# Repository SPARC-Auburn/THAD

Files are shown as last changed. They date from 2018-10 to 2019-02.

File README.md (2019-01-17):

# THAD
## The Helpful Automated Defender  

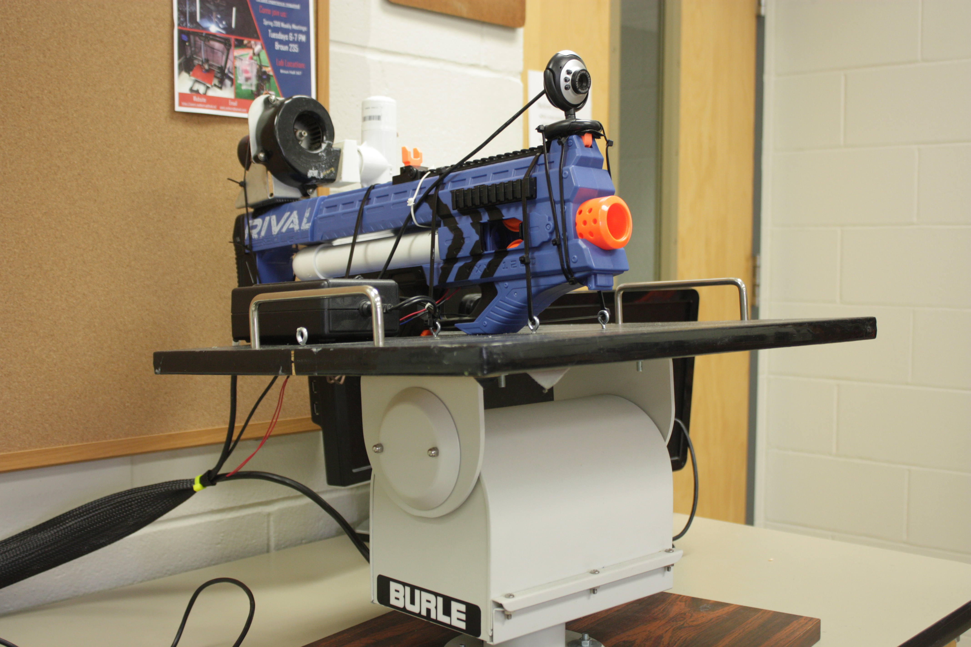
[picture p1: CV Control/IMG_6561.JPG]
THAD


## Project Purpose

THAD was previously a senior design project, and was given to SPARC in a state that did not operate. The goal of the project was to return it to working order and enable it with computer vision to be able to shoot the user's hand. This will facilitate a great project for demos and shows.

## Project Overview (NEEDS UPDATE)

The turret itself is mounted on a large, 2 axis motor, using a Nerf gun and seperate blower as its firing mechanism. The turret is controlled by a 5V 8-relay module to an Arduino. The arduino responds to serial commands. These commands are sent from various sources, and all that is required are (W,A,S,D,Q) characters to be sent over serial to operate. (These are Up, Left, Down, Right, and Fire respectively)

Using these serial commands, automatic control is also possible through OpenCV. The current version uses face recognition to determine targets, then crops a portion of the screen where the right hand might be relative to that face. Using the cropped image, it attempts to detect a right hand in a clenched fist. Future versions will ideally be able to handle multiple targets and a new haar cascade for an open hand.

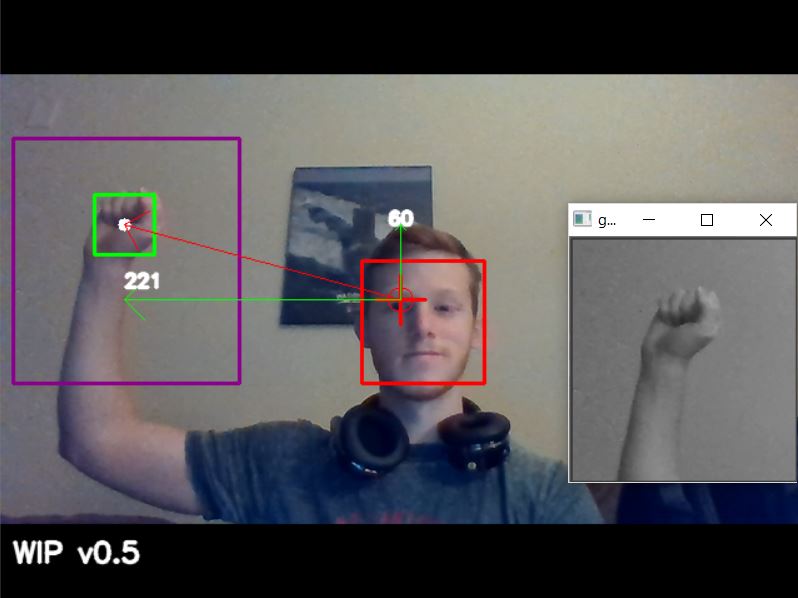
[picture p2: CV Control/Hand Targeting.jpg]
Face Recognition


## Setup and Use

### Manual (NEEDS UPDATE)

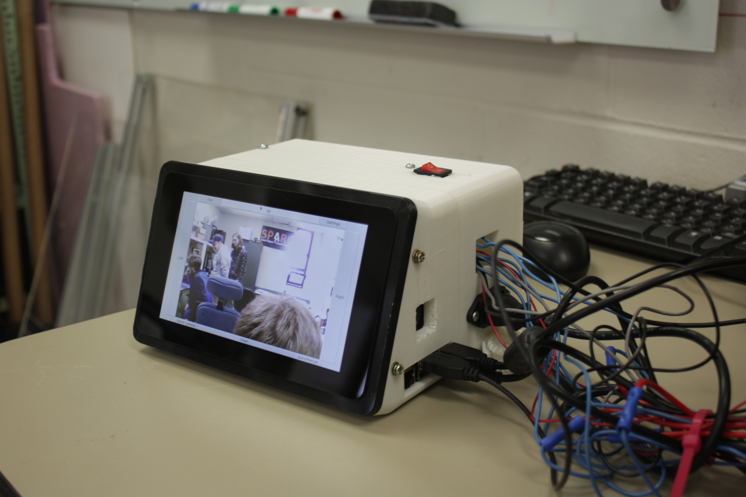
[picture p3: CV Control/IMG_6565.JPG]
Control Box


To run the turret manually via keyboard: 
1. Upload the .ino file located in the Manual folder to the Arduino. 
1. The Arduino pinout should be as follows:
  * DIO2 - Fire(Fan)
  * DIO3 - Flywheel(Trigger)
  * DIO4 - Up
  * DIO5 - Down
  * DIO6 - CW(Right)
  * DIO7 - CCW(Left)
  * Note: The Fan requires 27VDC
3. With the a PC still plugged in to the Arduino, run the keyboardserial.py program
  * You may have to change the port in the .py code. Simply change "COM3" to the port the Arduino is plugged into.
4. With the PyGame window active, use the keys W,A,S,D and Q to control the turret.  

### OpenCV(Computer Vision) (NEEDS UPDATE)

To run the turret via OpenCV:
1. Ensure Python 2.7 and OpenCV are compiled and usable natively from your OS Path.
1. Follow Step 2 from above to properly wire the turret.
1. Plug your computer into the webcam and Arduino located on THAD
1. Run the main.py program- it will currently only fire at a person's hand, and does not work well with multiple faces detected in the frame.
1. Get ready!

## Future Improvements

## References

1. "Hand-raising gesture detection with Lienhart-Maydt method in videoconference and distance learning" http://conteudo.icmc.usp.br/pessoas/moacir/papers/NazarePonti_CIARP2013.pdf

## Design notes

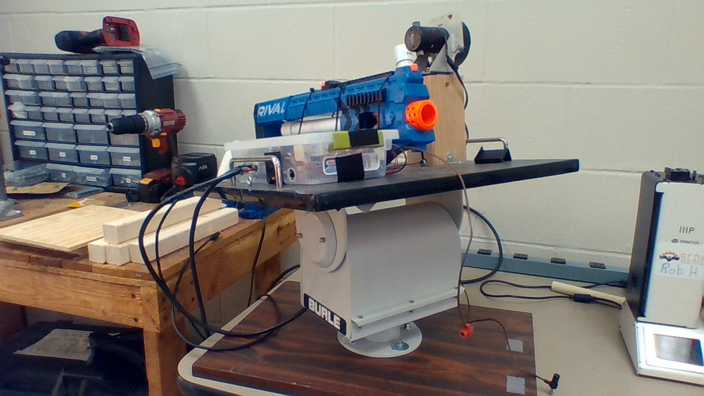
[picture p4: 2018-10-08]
img.jpg

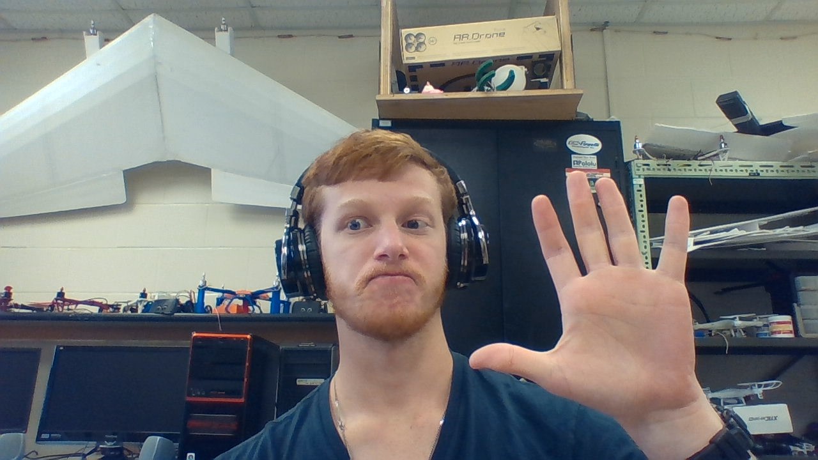
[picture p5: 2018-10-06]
CV_Control/handphoto.jpg

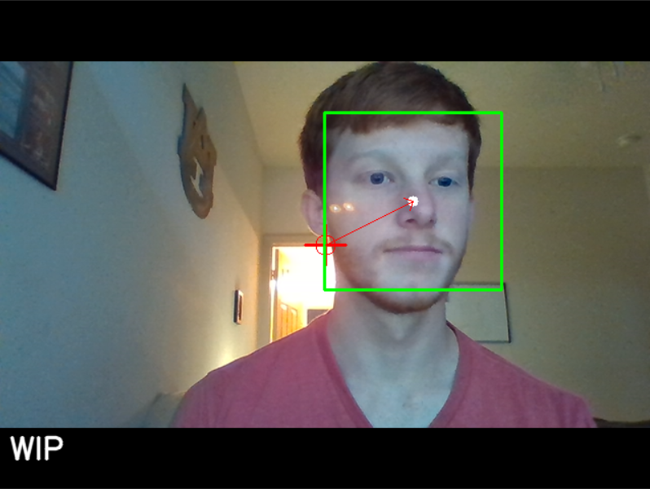
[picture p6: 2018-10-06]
CV_Control/Face Targeting.PNG

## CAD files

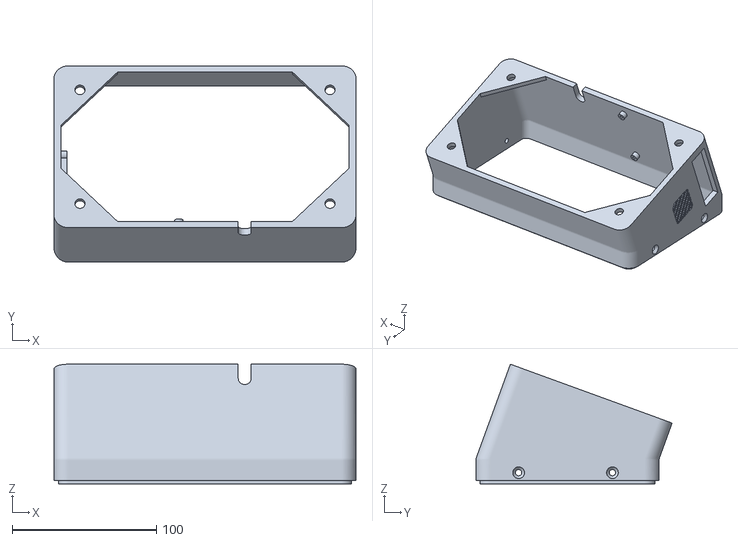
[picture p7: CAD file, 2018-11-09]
Control_Box/Wallmount_Back.stl
209.2 x 136.0 x 82.9

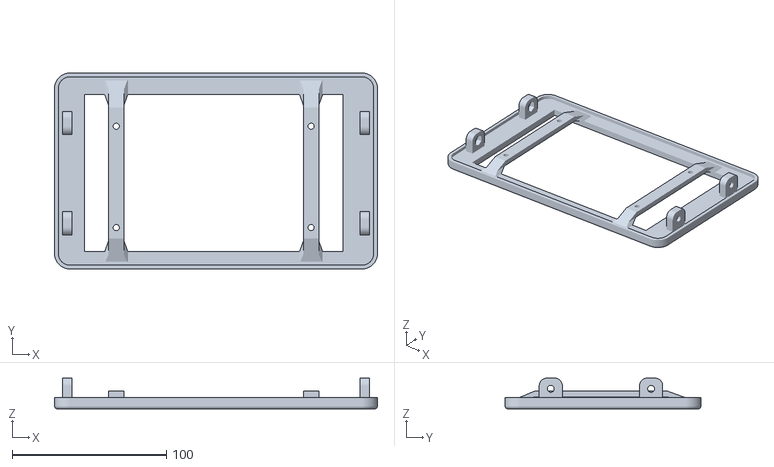
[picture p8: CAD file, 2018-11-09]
Control_Box/Wallmount_Front_Tessellation.3_1.stl
209.2 x 127.0 x 20.0

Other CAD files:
Control_Box/THAD Back.ipt

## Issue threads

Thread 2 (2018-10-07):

Webcam mount

joshjab, 2018-10-07:

joshjab, 2018-10-15:
Webcam is currently loosely attached to the Nerf gun's built in sight

joshjab, 2018-11-02:
Webcam mounted on top of turret

Closed 2018-11-02.

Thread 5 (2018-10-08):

Standalone Power Supply

joshjab, 2018-10-08:

joshjab, 2018-10-15:
Pi - 5VDC, 2A (Max)
Turret - 120VAC, ?A
Blower - 27VDC, .7A (Max)

joshjab, 2018-11-02:
Will be powered via 120VAC, removing this issue

Closed 2018-11-02.

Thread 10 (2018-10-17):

Swap out Arduino for Raspberry Pi GPIO

joshjab, 2018-10-17:

joshjab, 2018-11-02:
Duplicate Issue

Closed 2018-11-02.

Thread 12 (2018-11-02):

Ordering Parts

joshjab, 2018-11-02:
Needs:
- Pi Screen /w cable
AC/DC Converter
Wall plug w/ Female adapter

joshjab, 2018-11-02:
Power Switch

joshjab, 2018-11-05:
Parts ordered, except for PS

Closed 2018-11-05.

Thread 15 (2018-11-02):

Compile OpenCV on Pi and verify camera operation

joshjab, 2018-11-02:

joshjab, 2018-11-05:
Camera and detection works on Pi- new software release to come

joshjab, 2018-11-07:
Pi directly on turret does not work as expected. Reopening this issue

joshjab, 2018-11-09:
Fixed an issue with the haarcascades not properly being found. Camera works again- albeit slowly

Closed 2018-11-09.

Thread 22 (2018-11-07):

CAD Blower Joint

joshjab, 2018-11-07:
Old joint does not fit blower properly

joshjab, 2018-11-28:
Blower joint made and still is not a perfect fit- but it is adequate. May reopen this issue for V2

Closed 2018-11-28.

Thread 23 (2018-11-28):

Pi OpenCV Optimization

joshjab, 2018-11-28:
Recompiling OpenCV with better processor flags

joshjab, 2018-12-05:
Standalone optimization completed - still only 1 FPS, further improvement could be done- but it is no longer a current issue

Closed 2018-12-05.

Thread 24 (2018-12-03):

Restart USB when camera crashes

joshjab, 2018-12-03:

joshjab, 2018-12-06:
Reset Camera button added temporarily. Resets USB port and changes the index of the camera source back and forth from 0 to 1. Apparently the index changes when the camera reconnects

Closed 2018-12-06.

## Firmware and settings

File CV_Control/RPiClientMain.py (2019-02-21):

import Tkinter
import cv2
import PIL.Image, PIL.ImageTk
import time 
import socket
import numpy as np
import struct
pi = False
if pi:
    import RPi.GPIO as GPIO
    from USBReset import reset_USB_Device

##CONSTANTS##
#Pixel error margins
XMARGIN = 15
YMARGIN = 15  
#Camera position offsets
OFFSETX = 0
OFFSETY = 0
Pt1Y = 0
Pt2Y = 0
Pt2X = 0
Pt1X = 0
# Target Matched Variables (Controls firing)
XMatched = False
YMatched = False
#GPIO Pins UPDATE AS NEEDED
UP = 17
DOWN = 27
LEFT = 22
RIGHT = 23
FLYWHEEL = 24
BLOWER = 25
#Dev variables
standalone = 0
TCP_IP = '127.0.0.1'
PORT = 5005
font = cv2.FONT_HERSHEY_SIMPLEX

#RPi Setup
def GPIO_setup():
    GPIO.setmode(GPIO.BCM)
    GPIO.setwarnings(False)
    GPIO.setup(UP, GPIO.OUT)
    GPIO.setup(DOWN, GPIO.OUT)
    GPIO.setup(LEFT, GPIO.OUT)
    GPIO.setup(RIGHT, GPIO.OUT)
    GPIO.setup(FLYWHEEL, GPIO.OUT)
    GPIO.setup(BLOWER, GPIO.OUT)
    #Initial State Off
    GPIO.output(UP, GPIO.HIGH)
    GPIO.output(DOWN, GPIO.HIGH)
    GPIO.output(LEFT, GPIO.HIGH)
    GPIO.output(RIGHT, GPIO.HIGH)
    GPIO.output(FLYWHEEL, GPIO.HIGH)
    GPIO.output(BLOWER, GPIO.HIGH)

# Turret Control Function



def turnTurret( direction ):
    if(direction=="stopX"):
        GPIO.output(LEFT, GPIO.HIGH)   
        GPIO.output(RIGHT, GPIO.HIGH)
        print("X Matched")
    elif(direction=="stopY"):
        GPIO.output(UP, GPIO.HIGH)
        GPIO.output(DOWN, GPIO.HIGH)
        print("Y Matched")
    else:
        if(direction=="up"):
            GPIO.output(UP, GPIO.LOW)
            print("Moving up")
        elif(direction=="down"):
            GPIO.output(DOWN, GPIO.LOW)
            print("Moving down")
        elif(direction=="left"):
            GPIO.output(LEFT, GPIO.LOW)
            print("Moving left")
        elif(direction=="right"): 
            GPIO.output(RIGHT, GPIO.LOW)
            print("Moving right")

# Turret Fire Function

def fireTurret():
    GPIO.output(FLYWHEEL, GPIO.LOW)
    GPIO.output(BLOWER, GPIO.LOW)

#GPIO_setup() #UNCOMMENT THIS LINE FOR RUNNING ON RASPBERRY PI

 
class App:
    def __init__(self, window, window_title, video_source):
        self.window = window
        self.window.title(window_title)
        self.window.attributes('-fullscreen', True)
        self.video_source = video_source
        # open video source (by default this will try to open the computer webcam)
        self.vid = MyVideoCapture(self.video_source)
        self.autoMode = False
        self.standalone = Tkinter.BooleanVar()
        self.standalone.set(standalone)
        self.frame1 = Tkinter.Frame(window)
        self.frame1.pack()
        # Fire Button
        self.btn_fire=Tkinter.Button(self.frame1, text="Fire", width=10)
        self.btn_fire.pack(side=Tkinter.LEFT, anchor=Tkinter.NW, expand=True)
        self.btn_fire.bind('<ButtonPress-1>', self.fireon)
        self.btn_fire.bind('<ButtonRelease-1>', self.fireoff)
        # Up Button
        self.btn_up=Tkinter.Button(self.frame1, text="Up", width=50)
        self.btn_up.pack(side = Tkinter.LEFT, anchor=Tkinter.N, expand=True)
        self.btn_up.bind('<ButtonPress-1>', self.up)
        self.btn_up.bind('<ButtonRelease-1>', self.y_stop)
        # Settings Button
        self.btn_settings=Tkinter.Button(self.frame1, text="Settings", width=10, command=self.settings)
        self.btn_settings.pack(side = Tkinter.LEFT, anchor=Tkinter.NE, expand=True)


        self.frame2 = Tkinter.Frame(window)
        self.frame2.pack()
        # Left Button
        self.btn_left=Tkinter.Button(self.frame2, text="Left", height=30)
        self.btn_left.pack(side=Tkinter.LEFT, anchor=Tkinter.W)
        self.btn_left.bind('<ButtonPress-1>', self.left)
        self.btn_left.bind('<ButtonRelease-1>', self.x_stop)
        # Create a canvas that can fit the above video source size
        self.canvas = Tkinter.Canvas(self.frame2, width = self.vid.width, height = 430, background='black')
        self.canvas.pack(side=Tkinter.LEFT)
        # Right Button
        self.btn_right=Tkinter.Button(self.frame2, text="Right", height=30)
        self.btn_right.pack(side=Tkinter.LEFT, anchor=Tkinter.E)
        self.btn_right.bind('<ButtonPress-1>', self.right)
        self.btn_right.bind('<ButtonRelease-1>', self.x_stop)

        self.frame3 = Tkinter.Frame(window)
        self.frame3.pack()
	# Reset Button
        self.btn_reset=Tkinter.Button(self.frame3, text="Reset Camera",command = self.resetUSB)
        self.btn_reset.pack(side = Tkinter.LEFT)
        # Down Button 
        self.btn_down=Tkinter.Button(self.frame3, text="Down", width=50)
        self.btn_down.pack(side = Tkinter.LEFT)
        self.btn_down.bind('<ButtonPress-1>', self.down)
        self.btn_down.bind('<ButtonRelease-1>', self.y_stop)
        # Mode Button
        self.btn_down=Tkinter.Button(self.frame3, text="Auto/Manual", width=10, command=self.mode)
        self.btn_down.pack(side = Tkinter.LEFT, anchor=Tkinter.E)
        

        # After it is called once, the update method will be automatically called every delay milliseconds
        self.delay = 15

        self.initSockets()
        self.datum = [0,0,0,0,0,0,0,0,0,0,0,0]
        self.update()

        self.window.mainloop()
    def resetUSB(self):
        #reset_USB_Device()
        if (self.video_source == 0):
            self.video_source+=1
        else:
            self.video_source = 0
        self.vid = MyVideoCapture(self.video_source)
    def down(self, event):
        if pi:
            turnTurret("down")
        print "Moving down"

    def y_stop(self,event):
        if pi:
            turnTurret("stopY")
        print "Stopping Y Movement"

    def up(self,event):
        if pi:
            turnTurret("up")
        print "Moving up"

    def left(self,event):
        if pi:
            turnTurret("left")
        print "Moving left"

    def x_stop(self,event):
        if pi:
            turnTurret("stopX")
        print "Stopping X Movement"

    def right(self,event):
        if pi:
            turnTurret("right")
        print "Moving right"

    def fireon(self,event):
        if pi:
            fireTurret() 
        print "Firing"
    def fireoff(self,event):
        if pi:
            GPIO.output(BLOWER, GPIO.HIGH)
            GPIO.output(FLYWHEEL, GPIO.HIGH)
        print "Stopping fire sequence"

    def settings(self):
        self.settingsWindow = Tkinter.Toplevel(self.window)
        self.settingsWindow.title = "Settings"
        self.sframe1 = Tkinter.Frame(self.settingsWindow)
        self.sframe1.pack()
        self.standaloneOption = Tkinter.Radiobutton(self.sframe1, text="Standalone", variable=self.standalone, value=True).pack()
        self.remoteOption = Tkinter.Radiobutton(self.sframe1, text="Remote Processing", variable=self.standalone, value=False).pack()
        self.text = Tkinter.StringVar()
        self.output = Tkinter.Label(self.sframe1, textvariable=self.text).pack()
        self.text.set("Enable PC Connection")
        self.sframe2 = Tkinter.Frame(self.settingsWindow)
        self.sframe2.pack()
        self.connectButton = Tkinter.Button(self.sframe2, text="Test Connection", command=self.connectToPC).pack(side=Tkinter.LEFT )
        self.closeButton = Tkinter.Button(self.sframe2,text="Close",command=self.closeSettings).pack( side=Tkinter.LEFT )

    def connectToPC(self):
        print(self.standalone.get())
        '''TCP_IP = '127.0.0.1'
        TCP_PORT = 5005
        BUFFER_SIZE = 1024
        MESSAGE = "Hello, PC!"

        s = socket.socket(socket.AF_INET, socket.SOCK_STREAM)
        s.connect((TCP_IP, TCP_PORT))
        s.send(MESSAGE)
        data = s.recv(BUFFER_SIZE)
        s.close()

        self.text.set(data)'''

    def closeSettings(self):
        self.settingsWindow.destroy()

    def detectFaces(self, frame):
        if self.standalone.get():
            frameCenterX = ((frame.shape[1] / 2))
            frameCenterY = ((frame.shape[0] / 2))
            
            # Draw Statics
            
            #circle = cv2.circle(frame,(frameCenterX,frameCenterY), 2, (0,0,255), 1)    #Center Target
            #vline = cv2.line(frame,(frameCenterX,frameCenterY+5), (frameCenterX, frameCenterY-5), (0,0,255), 2)
            #hline = cv2.line(frame,(frameCenterX+5,frameCenterY), (frameCenterX-5, frameCenterY), (0,0,255), 2)
            hand_cascade = cv2.CascadeClassifier('../haarcascade_hand_alt.xml')   #TODO: Trained haarcascade  
            face_cascade = cv2.CascadeClassifier('../haarcascade_frontalface_default.xml')  
            gray = cv2.cvtColor(frame,cv2.COLOR_BGR2GRAY) #Convert to grayscale
            faces = face_cascade.detectMultiScale(gray, 1.1, 5) #Detect faces
            for(x,y,w,h) in faces:
                #cv2.rectangle(frame,(x,y),(x+w,y+h),(0,0,255),2) #Display box for viewer  
                print str(len(faces)) + " face(s) found"
            if (len(faces)== 1): #Detected 1 face and in standalone mode
                Pt1X = x-w #Tuned constants for rough area of arm location based on size of face 
                if Pt1X < 20: #Must be positive
                    Pt1X = 20
                Pt1Y = y+h
                if Pt1Y < 20:
                    Pt1Y = 20
                Pt2X = x-(3*w)
                if Pt2X < 10:
                    Pt2X = 10
                Pt2Y = y-h
                if Pt2Y < 10:
                    Pt2Y = 10
                cv2.rectangle(frame, (Pt1X,Pt1Y),(Pt2X,Pt2Y),(139,0, 139),2) #Rectangle is hidden so it does not show up in cropped image
                cropped = frame[Pt2Y:Pt1Y, Pt2X:Pt1X]   #Crop image to expected area where hand would be   
                if cropped.size >= 0:                                    
                    grey_cropped = cv2.cvtColor(cropped, cv2.COLOR_BGR2GRAY)
                    hands = hand_cascade.detectMultiScale(grey_cropped, 1.1, 5)      
                    for (x,y,w,h) in hands:
                        cv2.rectangle(frame,(x+Pt2X,y+Pt2Y),(x+w+Pt2X,y+h+Pt2Y),(0,0,255),2)
                        if(len(hands) == 1): #1 hand found, draw target, vector and turn towards target
                            print "Target found!"
                            target = cv2.rectangle(frame,(x+Pt2X,y+Pt2Y),(x+w+Pt2X,y+h+Pt2Y),(0,255,0),2)
                            targetCenterX = (x+Pt2X +(w/2))
                            targetCenterY = (y+Pt2Y+(h/2))
                            #targetCenterShow =  cv2.circle(frame,(targetCenterX, targetCenterY), 5, (255,255,255), -1)

                            #Draw Vector to Target
                            distanceX = frameCenterX-targetCenterX
                            #cv2.putText(frame,str(distanceX),(frameCenterX-distanceX,frameCenterY-10), font, .5,(255,255,255),2,cv2.LINE_AA)
                            distanceY = frameCenterY-targetCenterY
                            #cv2.putText(frame,str(distanceY),(frameCenterX-10,frameCenterY-distanceY), font, .5,(255,255,255),2,cv2.LINE_AA)
                            #vector = cv2.arrowedLine(frame, (frameCenterX, frameCenterY), (targetCenterX, targetCenterY), (0,0,255), 1)
                            #vectorX = cv2.arrowedLine(frame, (frameCenterX, frameCenterY), (targetCenterX, frameCenterY), (0,255,0), 1)
                            #vectorY = cv2.arrowedLine(frame, (frameCenterX, frameCenterY), (frameCenterX, targetCenterY), (0,255,0), 1)    
                            # Adjust X axis
                             #Negative
                            if(distanceX<-1*XMARGIN):
                                self.right(None)
                             #Positive
                            elif(distanceX>XMARGIN):
                                self.left(None)
                             #XMatched
                            else:
                                self.x_stop(None)
                            #Adjust Y axis
                            #Negative
                            if(distanceY<-1*YMARGIN):
                                self.down(None)
                            #Positive
                            elif(distanceY>YMARGIN):
                                self.up(None)
                            else:
                                self.y_stop(None)
                            return True
                        else:
                            print "No hands found"
                            return False
            else:
                print "More than one face found"
                return False
        elif self.connected:
            frameCenterX = ((frame.shape[1] / 2))
            frameCenterY = ((frame.shape[0] / 2))
            encode_param=[int(cv2.IMWRITE_JPEG_QUALITY),100]
            result, imgencode = cv2.imencode('.jpg', frame, encode_param)
            stringData = imgencode.tostring()
            try:
                #time.sleep(.0001) #otherwise send to fast and the server receive images in pieces and fail
                self.send.send( str(len(stringData)).ljust(16))
                self.send.send(stringData)
                try:
                    rec = self.conn.recv(4*12)
                    print(len(rec))
                    self.datum = struct.unpack("iiiiiiiiiiii",rec)
                except socket.error:
                    pass
                (fx,fy,fw,fh,sx,sy,sw,sh,hx,hy,hw,hh) = self.datum
                if fx >= 0:
                    cv2.rectangle(frame,(fx,fy),(fx+fw,fy+fh),(0,0,255),3)
                    cv2.rectangle(frame,(sx,sy),(sx+sw,sy+sh),(255,0,255),3)
                    if hx >= 0:
                        cv2.rectangle(frame,(hx,hy),(hx+hw,hy+hh),(0,255,0),3)
                        targetCenterX = (hx +(hw/2))
                        targetCenterY = (hy+(hh/2))
                        distanceX = frameCenterX-targetCenterX
                        distanceY = frameCenterY-targetCenterY 
                        # Adjust X axis
                            #Negative
                        if(distanceX<-1*XMARGIN):
                            self.right(None)
                            #Positive
                        elif(distanceX>XMARGIN):
                            self.left(None)
                            #XMatched
                        else:
                            self.x_stop(None)
                        #Adjust Y axis
                        #Negative
                        if(distanceY<-1*YMARGIN):
                            self.down(None)
                        #Positive
                        elif(distanceY>YMARGIN):
                            self.up(None)
                        else:
                            self.y_stop(None)
                        return True
            except socket.error as e:
                print(e)
                self.connected = False
                self.conn.close()
                self.send.close()
                self.conn = False
                self.initSockets()



    def mode(self):    
        self.autoMode = not self.autoMode
        print "autoMode is " + str(self.autoMode)
        
    def initSockets(self):
        self.s = socket.socket(socket.AF_INET, socket.SOCK_STREAM)
        self.s.bind((TCP_IP, PORT+1))
        self.s.setblocking(False)
        self.s.listen(1)
        self.connected = False
        self.conn = False
        self.send = socket.socket(socket.AF_INET,socket.SOCK_STREAM)
    def update(self):
        #try:
        
            # Get a frame from the video source
        ret, frame = self.vid.get_frame()
        try:
            conn2, addr = self.s.accept()
            print "Got connection"
            if self.conn:
                conn.close()
            self.conn = conn2
            self.conn.setblocking(False)
            self.send.connect((addr[0],PORT))
            self.connected = True
        except socket.error:
            pass
        if ret:
            global font
            if self.autoMode:
                if self.standalone.get() == 1:
                    
                    imageResize = cv2.resize(frame, None, fx = 0.65, fy = 0.65)
                    if not (self.detectFaces(imageResize)):
                        self.x_stop(None)
                        self.y_stop(None)
                    cv2.putText(imageResize, 'AUTO', (50,70), font, .75, (255,0,0),2,cv2.LINE_AA)
                    self.photo = PIL.ImageTk.PhotoImage(image = PIL.Image.fromarray(imageResize))
                    self.canvas.create_image(self.canvas.winfo_width()/2, self.canvas.winfo_height()/2, image = self.photo, anchor = Tkinter.CENTER)
                else:
                    
                    if not (self.detectFaces(frame)):
                        self.x_stop(None)
                        self.y_stop(None)
                    cv2.putText(frame, 'AUTO', (50,70), font, .75, (255,0,0),2,cv2.LINE_AA)
                    if(self.connected):
                        cv2.putText(frame, 'CONN', (50,90), font, .75, (255,255,0),2,cv2.LINE_AA)
                    self.photo = PIL.ImageTk.PhotoImage(image = PIL.Image.fromarray(frame))
                    self.canvas.create_image(self.canvas.winfo_width()/2, self.canvas.winfo_height()/2, image = self.photo, anchor = Tkinter.CENTER)
            else:
                self.photo = PIL.ImageTk.PhotoImage(image = PIL.Image.fromarray(frame))
                self.canvas.create_image(self.canvas.winfo_width()/2, self.canvas.winfo_height()/2, image = self.photo, anchor = Tkinter.CENTER)
        #except:
        self.window.after(self.delay, self.update)
        

class MyVideoCapture:
    def __init__(self, video_source):
       # Open the video source
        self.vid = cv2.VideoCapture(video_source)
        if not self.vid.isOpened():
            raise ValueError("Unable to open video source", video_source)

        # Get video source width and height
        self.width = self.vid.get(cv2.CAP_PROP_FRAME_WIDTH)
        self.height = self.vid.get(cv2.CAP_PROP_FRAME_HEIGHT)

    def get_frame(self):
        if self.vid.isOpened():
            ret, frame = self.vid.read()
            if ret:
                # Return a boolean success flag and the current frame converted to BGR
                return (ret, cv2.cvtColor(frame, cv2.COLOR_BGR2RGB))
            else:
                return (ret, None)
        else:
            return (ret, None)

    # Release the video source when the object is destroyed
    def __del__(self):
        if self.vid.isOpened():
            self.vid.release()
        if self.connected:
            self.send.close()
            self.s.close()
            self.conn.close()

# Create a window and pass it to the Application object
App(Tkinter.Tk(), "Tkinter and OpenCV", 0)

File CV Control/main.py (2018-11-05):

import numpy as np
import cv2
import serial
import sys
import time
import math
##CONSTANTS##
#Pixel error margins
XMARGIN = 30
YMARGIN = 30  
#Camera position offsets
OFFSETX = 0
OFFSETY = 0
Pt1Y = 0
Pt2Y = 0
Pt2X = 0
Pt1X = 0
###

cap = cv2.VideoCapture(1)
try:
    ser = serial.Serial("COM3")
    connected = True
except:
    print("No Serial Connection to turret found")
    connected = False
while(True):
##### Capture frame-by-frame
    ret, frame = cap.read()
    frameCenterX = ((frame.shape[1] / 2) + OFFSETX)
    frameCenterY = ((frame.shape[0] / 2) + OFFSETY)
##### Drawing Static Images
    circle = cv2.circle(frame,(frameCenterX,frameCenterY), 10, (0,0,255), 1)    #Center Target
    vline = cv2.line(frame,(frameCenterX,frameCenterY+20), (frameCenterX, frameCenterY-20), (0,0,255), 2)
    hline = cv2.line(frame,(frameCenterX+20,frameCenterY), (frameCenterX-20, frameCenterY), (0,0,255), 2)
    font = cv2.FONT_HERSHEY_SIMPLEX                             #WIP
    cv2.putText(frame,'WIP v0.5',(10,450), font, .75,(255,255,255),2,cv2.LINE_AA)

##### Detect Faces
    face_cascade = cv2.CascadeClassifier('C:\Users\joshj\Downloads\opencv\sources\data\haarcascades\haarcascade_frontalface_default.xml')  
    gray = cv2.cvtColor(frame,cv2.COLOR_BGR2GRAY) #Convert to grayscale
    faces = face_cascade.detectMultiScale(gray, 1.1, 5) #Detect faces

    #Detect Hands
    #Define search space for hands based on face detection and size of face
    for(x,y,w,h) in faces:
        cv2.rectangle(frame,(x,y),(x+w,y+h),(0,0,255),2)
        Pt1X = x-w #Tuned constants for rough area of arm location based on size of face 
        if Pt1X < 20: #Must be positive
            Pt1X = 20
        Pt1Y = y+h
        if Pt1Y < 20:
            Pt1Y = 20
        Pt2X = x-(3*w)
        if Pt2X < 10:
            Pt2X = 10
        Pt2Y = y-h
        if Pt2Y < 10:
            Pt2Y = 10
        cv2.rectangle(frame, (Pt1X,Pt1Y),(Pt2X,Pt2Y),(139,0, 139),2) #Rectangle is hidden so it does not show up in cropped image
        print str(len(faces))+" face(s) found"
    #Try to find hands in search frame using contour detection
    hand_cascade = cv2.CascadeClassifier('C:\Users\joshj\Downloads\opencv\sources\data\haarcascades\haarcascade_hand_alt.xml')   #TODO: Trained haarcascade
    if len(faces) > 0:
        cropped = frame[Pt2Y:Pt1Y, Pt2X:Pt1X]   #Crop image to expected area where hand would be                                       
        grey_cropped = cv2.cvtColor(cropped, cv2.COLOR_BGR2GRAY)
        hands = hand_cascade.detectMultiScale(grey_cropped, 1.1, 5)      
        for (x,y,w,h) in hands:
            cv2.rectangle(frame,(x+Pt2X,y+Pt2Y),(x+w+Pt2X,y+h+Pt2Y),(0,0,255),2)
            print "(" + str(x-Pt2X) + "," + str(y-Pt2Y) +")"
        cv2.imshow('gray_crop',grey_cropped)
        print str(len(hands)) + " hand(s) found"
    #Display potential objects

##### Determine if pose is valid
        targetFound = False
        if (len(hands) == 1):   #Detect if there is one valid hand                                                                  
            targetFound = True
            for (x,y,w,h) in hands:
                target = cv2.rectangle(frame,(x+Pt2X,y+Pt2Y),(x+w+Pt2X,y+h+Pt2Y),(0,255,0),2)
                targetCenterX = (x+Pt2X +(w/2))
                targetCenterY = (y+Pt2Y+(h/2))
                targetCenterShow =  cv2.circle(frame,(targetCenterX, targetCenterY), 5, (255,255,255), -1)

    ##### Move object center using serial connection

        # Check and adjust until center is within error range
        if(targetFound):
            vector = cv2.arrowedLine(frame, (frameCenterX, frameCenterY), (targetCenterX, targetCenterY), (0,0,255), 1)
            vectorX = cv2.arrowedLine(frame, (frameCenterX, frameCenterY), (targetCenterX, frameCenterY), (0,255,0), 1)
            vectorY = cv2.arrowedLine(frame, (frameCenterX, frameCenterY), (frameCenterX, targetCenterY), (0,255,0), 1)


    ###### Try to move the pose center to the frame center (close to it) 
            distanceX = frameCenterX-targetCenterX
            cv2.putText(frame,str(distanceX),(frameCenterX-distanceX,frameCenterY-10), font, .5,(255,255,255),2,cv2.LINE_AA)
            distanceY = frameCenterY-targetCenterY
            cv2.putText(frame,str(distanceY),(frameCenterX-10,frameCenterY-distanceY), font, .5,(255,255,255),2,cv2.LINE_AA)
            if(connected):
                #Vector to target
                #Adjust X axis
                #Negative
                if(distanceX<-1*XMARGIN):
                    ser.write('d')  #Move right
                    ser.write('f')  #Stop moving left
                    print("Moving right")
                #Positive
                elif(distanceX>XMARGIN):
                    ser.write('a')  #Move left
                    ser.write('h')  #Stop moving right
                    print("Moving left")
                else:
                    ser.write('f')  #Stop all
                    ser.write('h')
                    print("X matched")
                #Adjust Y axis
                #Negative
                if(distanceY<-1*YMARGIN):
                    ser.write('s')  #Move down
                    ser.write('t')  #Stop moving up
                    print("Moving down")
                #Positive
                elif(distanceY>YMARGIN):
                    ser.write('w')  #Move up
                    ser.write('g')  #Stop moving down
                    print("Moving up")
                else:
                    ser.write('t')  #Stop all
                    ser.write('g')
                    print("Y matched")
            else:
                print("Found target- but not connected to turret")
        else:   #Valid target not found- stop turret
            if(connected):
                ser.write('t')
                ser.write('g')
                ser.write('h')
                ser.write('f')

    ###### Display the resulting frame
        if cv2.waitKey(1) & 0xFF == ord('q'):
            if(connected):  #Stop turret
                ser.write('t')
                ser.write('g')
                ser.write('h')
                ser.write('f')
            break

# When everything done, release the capture
cap.release()
cv2.destroyAllWindows()

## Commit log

2018-09-04 Manual control via Arduino and KeyboardSerial
2018-10-06 CV Control - Face targeting
    Since facial recognition is currently more simple to do for creating a first test, this program now targets the center of a face and points a vector from the center of the face to the center of the s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
2018-10-08 Motor Control added
2018-10-11 Changed error margins and now uses webcam
    [main.py]
2018-11-09 Control Box Parts
    Back needs mounting holes and acryllic window piece
    [THAD Back.ipt, Wallmount_Back.stl, Wallmount_Front_Tessellation.3_1.stl]
2018-11-14 Pi Pin Update and added mainWindow class
2018-12-03 Upload of example code to reset USB
    [USBReset.py]
2019-02-05 Renamed the folders because I'm not a heathen
    [THAD Back.ipt, Wallmount_Back.stl, Wallmount_Front_Tessellation.3_1.stl]
2019-02-18 Ensure server pulls all previous sent frames before processing. Prevents a buffer build up and thus decresease latency
